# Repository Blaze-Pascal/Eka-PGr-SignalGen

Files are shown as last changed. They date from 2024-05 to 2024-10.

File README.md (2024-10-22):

# Eka-PGr-SignalGen

Eka-PGr-SignalGen is a project designed for signal generation circuits, featuring schematic and PCB design using KiCad and simulations in LTSpice. It includes a Bill of Materials for easy component sourcing.
Features:

    KiCad project files for PCB design
    LTSpice simulation files
    BOM generation for parts

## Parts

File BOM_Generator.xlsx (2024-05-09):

 |  |  |  |  | X= | 2
lp. | ELEMENT | SYMBOL | ILOSC 1 | CENA ZA 1 | KOD TME | ILOSC NA X | CENA ZA X | OBUDOWA | LINK
1. | LM337 | LM337_TO220 | 1 | 4.332 | LM337SP | 2 | 8.664 | TO220 | https://www.tme.eu/pl/details/lm337sp/stabilizatory-napiecia-regulowane/stmicroelectronics/
2. | LM317 | LM317_TO-220 | 1 | 3.076 | LM317MABTG | 2 | 6.152 | TO220 | https://www.tme.eu/pl/details/lm317mabtg/stabilizatory-napiecia-regulowane/onsemi/
3. | LM7805 | LM7805_TO220 | 1 | 1.364 | LM7805-CDI | 2 | #VALUE! | TO220 | https://www.tme.eu/pl/details/lm7805-cdi/stabilizatory-napiecia-nieregulowane/cdil/lm7805/
4. | MC34063 | MC34063AP | 1 | 1.113 | MC34063AGN-TT | 2 | #VALUE! | DIP8 | https://www.tme.eu/pl/details/mc34063agn-tt/regulatory-napiecia-uklady-dc-dc/taejin-technology-htc-korea/mc34063agn/
5. |  |  |  | 2.365 | MC34063ACN | 0 | #VALUE! | DIP8 | https://www.tme.eu/pl/details/mc34063acn/regulatory-napiecia-uklady-dc-dc/stmicroelectronics/
6. | 1N4007 | 1N4007 | 4 | 0.7852 | 1N4007FLTR-SMC | 8 | 6.2816 | SOD123F | https://www.tme.eu/pl/details/1n4007fltr-smc/diody-uniwersalne-smd/smc-diode-solutions/1n4007fltr/
7. |  |  |  |  |  | 0 | 0
8. | LM318 | LM318H | 1 | 4.116 | LM318N/NOPB | 2 | 8.232 | DIP8 | https://www.tme.eu/pl/details/lm318n_nopb/wzmacniacze-operacyjne-tht/texas-instruments/
9. | BD135 | BD135 | 1 | 0.729 | BD135-16-CDI | 2 | 1.458 | TO126 | https://www.tme.eu/pl/details/bd135-16-cdi/tranzystory-npn-tht/cdil/tbd135-16/
10. | BD136 | BD136 | 1 | 0.639 | BD136-16-CDI | 2 | 1.278 | TO126 | https://www.tme.eu/pl/details/bd136-16-cdi/tranzystory-pnp-tht/cdil/tbd136-16/
11. | 1N4118 | 1N4118 | 2 | 0.3899 | 1N4148TA | 4 | 1.5596 | DO35 | https://www.tme.eu/pl/details/1n4148ta/diody-uniwersalne-tht/onsemi/
12. | Kondensator 3,3p | C13 | 1 | 0.6305 | 08055A3R3CAT2A | 2 | 1.261 | 805 | https://www.tme.eu/pl/details/08055a3r3cat2a/kondensatory-mlcc-smd/kyocera-avx/
13. | Kondensator 100n |  | 9 | 0.314 | CC0805KKX7R0BB104 | 18 | 5.652 | 805 | https://www.tme.eu/pl/details/cc0805kkx7r0bb104/kondensatory-mlcc-smd/yageo/
14. | Kondensator 100u | C4,C6,C11,C12, C18, C19 | 6 | 0.554 | UVY1E101MDD | 12 | 6.648 | Radial 5mm | https://www.tme.eu/pl/details/uvy1e101mdd/kondensatory-elektrolityczne-tht/nichicon/
15. | Kondensator 470p | C5 | 1 | 0.53 | 08055A471JAT2A | 2 | 1.06 | 805 | https://www.tme.eu/pl/details/08055a471jat2a/kondensatory-mlcc-smd/kyocera-avx/
16. | Kondensator 10u |  | 4 | 0.334 | GRC00AA1001HTNL | 8 | 2.672 | 5x11mm | https://www.tme.eu/pl/details/grc00aa1001htnl/kondensatory-elektrolityczne-tht/vishay/
17. |  |  |  |  |  | 0 | 0
18. |  |  |  |  |  | 0 | 0
19.
20. | Rezystor 0,2 | R1 | 1 |  | ? | 2 | 0 | 805 | ?
21. | Rezystor 18k | R3 | 1 | 0.1 | ERJ6ENF1802V | 2 | 0.2 | 805 | https://www.tme.eu/pl/details/erj6enf1802v/rezystory-smd/panasonic/
22. | Potencjometr 1k | R4, R5, R37 | 3 | 1.12 | 3305SMD-1K | 6 | 6.72 | ? | https://www.tme.eu/pl/details/3305smd-1k/potencjometry-smd-jednoobrotowe/sr-passives/
23. | Rezystor 100 | R6,R7,R39,R40 | 4 | 0.26 | RT0805FRE07100RL | 8 | 2.08 | 805 | https://www.tme.eu/pl/details/rt0805fre07100rl/rezystory-smd/yageo/
24. | Rezystor 20k | R32 | 1 | 0.218 | ERJ6ENF2002V | 2 | 0.436 | 805 | https://www.tme.eu/pl/details/erj6enf2002v/rezystory-smd/panasonic/
25. | Rezystor x | R33 |  |  |  | 0 | 0 | 805
26. | Rezystor x | R34 |  |  |  | 0 | 0 | 805
27. | Rezystor 27 | R35 | 1 | 0.582 | AR0805-27R-0.1% | 2 | 1.164 | 805 | https://www.tme.eu/pl/details/ar0805-27r-0.1%25/rezystory-smd/viking/ar05btcw0270/
 | Rezystor 1k | R36, R38 | 2 | 0.133 | ERJ6ENF1001V | 4 | 0.532 | 805 | https://www.tme.eu/pl/details/erj6enf1001v/rezystory-smd/panasonic/
 | Rezystor 3,3 | R41, R42 | 2 | 0.61 | CRCW25123R30JNTHBC | 4 | 2.44 | 2512 | https://www.tme.eu/pl/details/crcw25123r30jnthbc/rezystory-smd/vishay/
 | Rezystor 2k 0,1% |  |  |  |  | 0 | 0
 | Rezystor 100 1w |  | 2 | 0.354 | CRCW2512100RJNTHBC |  |  | 2512 | https://www.tme.eu/pl/details/crcw2512100rjnthbc/rezystory-smd/vishay/
 | Dioda 1N5818 | D2 | 1 | 1.29 | 1N5818-DC | 2 | 2.58 | DO41 | https://www.tme.eu/pl/details/1n5818-dc/diody-schottky-tht/dc-components/1n5818/
 | Dioda 1N4007 | D3,D4,D5,D6 | 4 | 0.728 | 1N4007FLTR-SMC | 8 | 5.824 | SOD123F | https://www.tme.eu/pl/details/1n4007fltr-smc/diody-uniwersalne-smd/smc-diode-solutions/1n4007fltr/
 | Dioda 1N4148 | D7, D8 | 2 | 0.159 | 1N4148W-AQ-DIO | 4 | 0.636 | SOD123F | https://www.tme.eu/pl/details/1n4148w-aq-dio/diody-uniwersalne-smd/diotec-semiconductor/1n4148w-aq/
 |  |  |  |  |  | 0 | 0
 | Cewka 100u | L1 | 1 | 4.85 | SBC4-101-102 | 2 | 9.7 |  | https://www.tme.eu/pl/details/sbc4-101-102/dlawiki-pionowe/kemet/
 |  |  |  | 1.39 | RLB0914-101KL | 0 | 0 |  | https://www.tme.eu/pl/details/rlb0914-101kl/dlawiki-pionowe/bourns/
 | Złącze BNC | Conn_Coaxial | 1 | 7.37 | RF15006 | 2 | 14.74 | BNC | https://www.tme.eu/pl/details/rf15006/zlacza-bnc/adam-tech/rf1-500-6/
 |  |  | 1 | 9.75 | B6252H5NPP3G50 | 2 | 19.5 | BNC | https://www.tme.eu/pl/details/b6252h5npp3g50/zlacza-bnc/amphenol-rf/b6252h5-npp3g-50/
 |  |  |  |  |  | 0 | 0
 | Tranzystor BC817 | Q3 | 1 | 0.111 | BC817-QR | 2 | 0.222 | SOT23 | https://www.tme.eu/pl/details/bc817-qr/tranzystory-npn-smd/nexperia/
 | Przekaźnik |  | 1 | 1.922 | LEG-1A-5 | 2 | 3.844 | ? | https://www.tme.eu/pl/details/leg-1a-5/przekazniki-elektromagn-miniaturowe/recoy-rayex-electronics/leg1a-5/
 |  |  |  |  |  | 0 | 0
 |  |  |  |  |  | 0 | 0
 | Bezpiecznik topikowy |  |  |  |  | 0 | 0
 | Gniazdo bezpiecznikowe |  |  |  |  | 0 | 0

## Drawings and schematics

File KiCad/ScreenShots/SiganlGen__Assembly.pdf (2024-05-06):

A

A

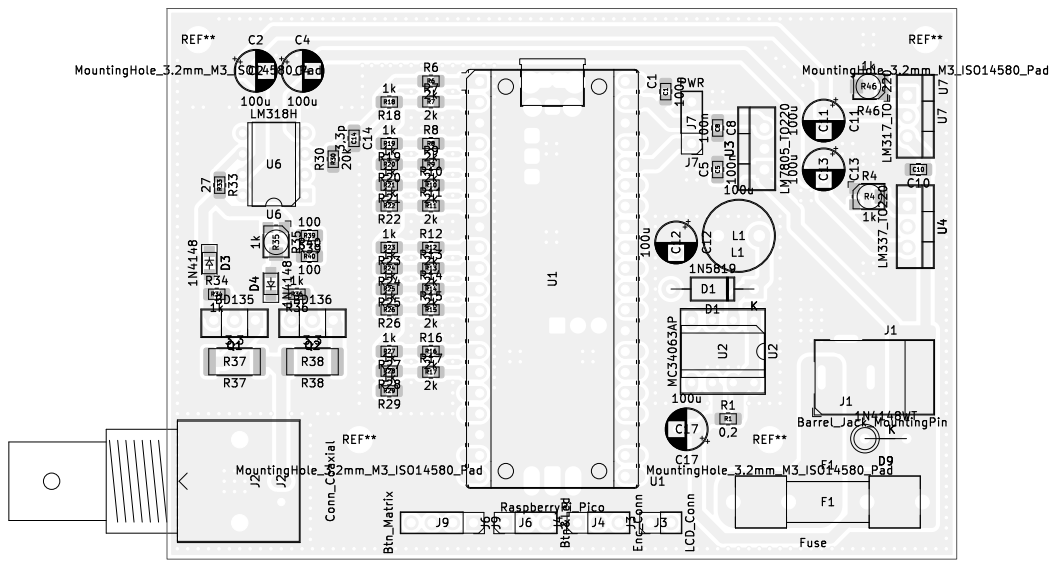
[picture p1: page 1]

Id: 1/1 Title: File: SiganlGen.kicad_pcb Sheet:

C19 C3 D7 | R2 | C18 C16 1 | 2 | 3 | 4 | 5 | 6 1 | 2 | 3 | 4 | 5 | 6 ABCD | ABCD Date: KiCad | E.D.A. 8.0.1 Size: A4 | Rev:
C18 100n | C16

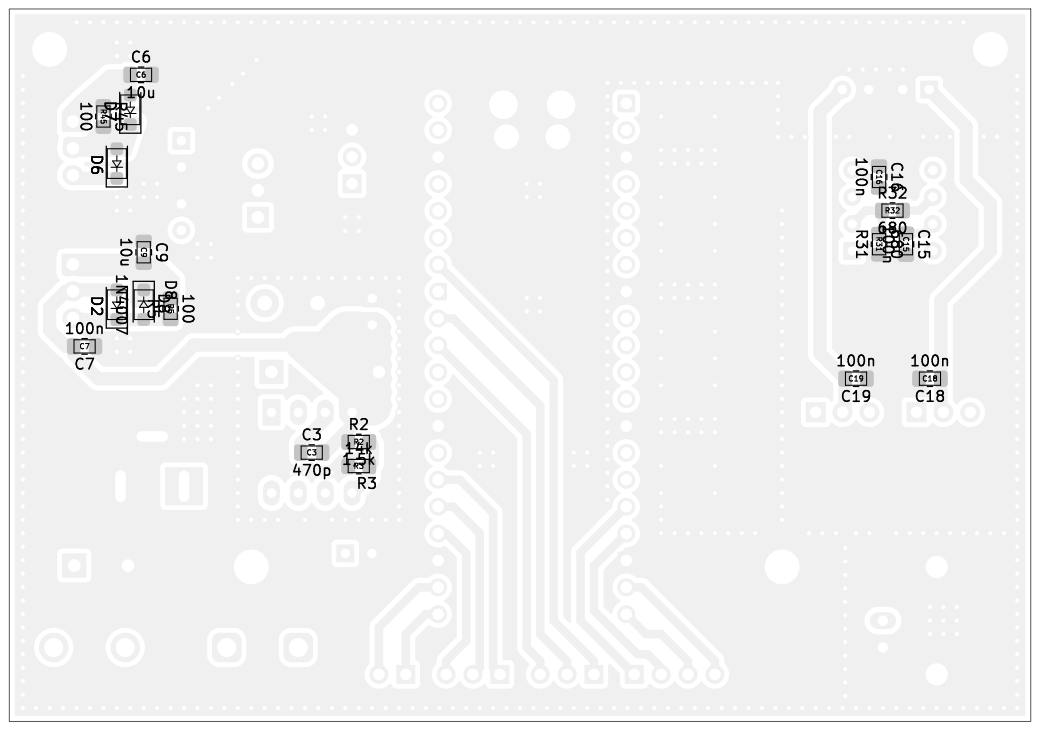
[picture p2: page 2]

Id: 1/1 Title: File: SiganlGen.kicad_pcb Sheet:

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

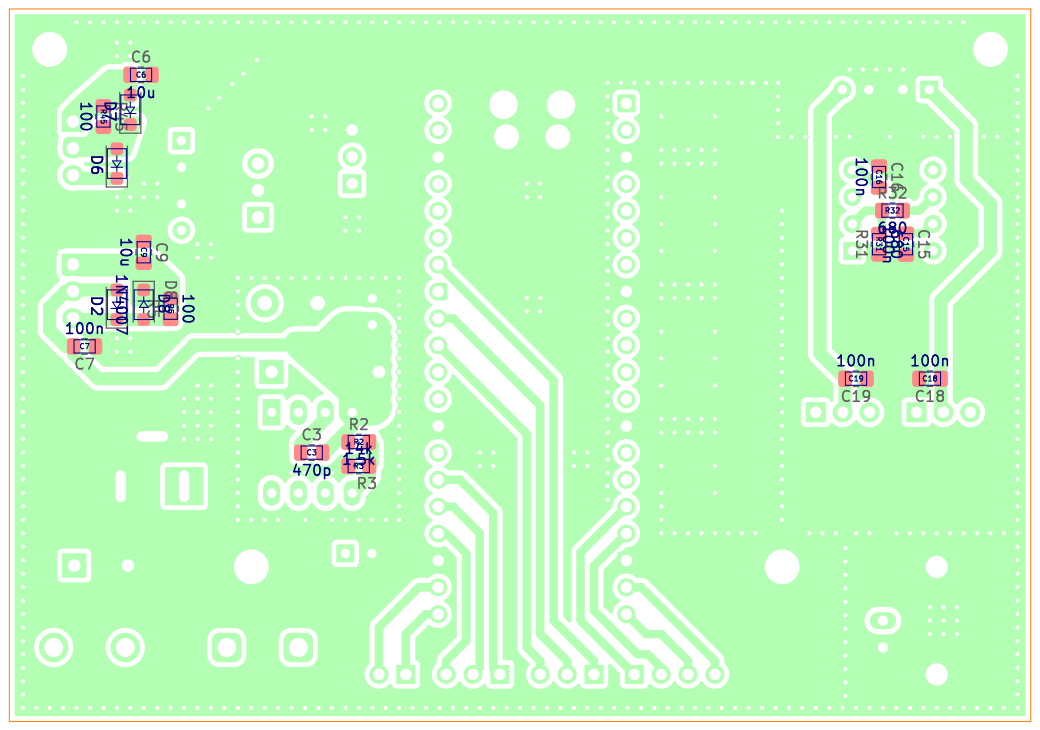
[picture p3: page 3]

Id: 1/1 Title: File: SiganlGen.kicad_pcb Sheet:

A

A

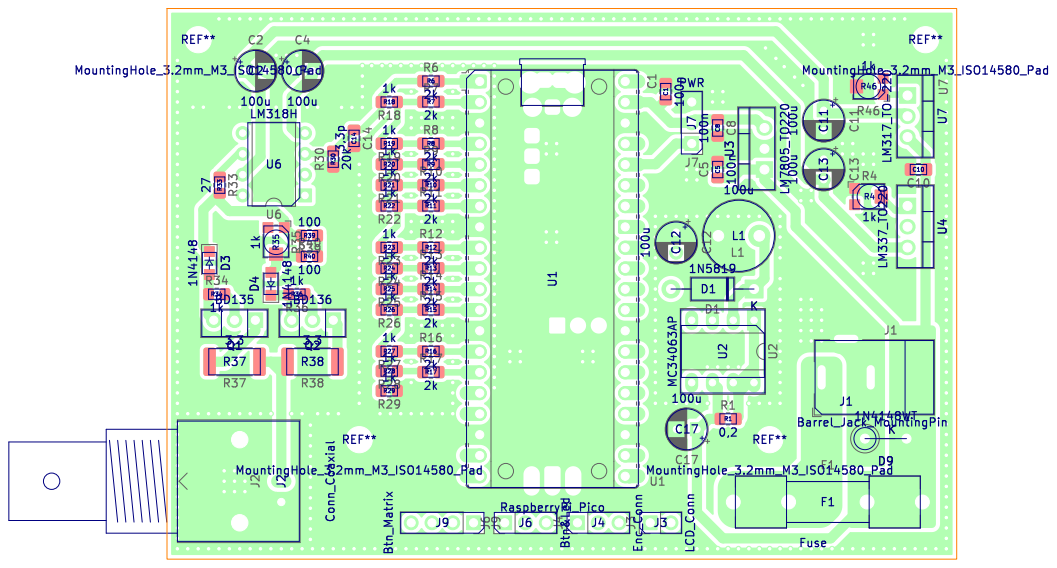
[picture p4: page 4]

Id: 1/1 Title: File: SiganlGen.kicad_pcb Sheet:

# Out Exposed Copper Keep Out Board Keep Out USB Cable USB Cable

## circle shown Wiper may be

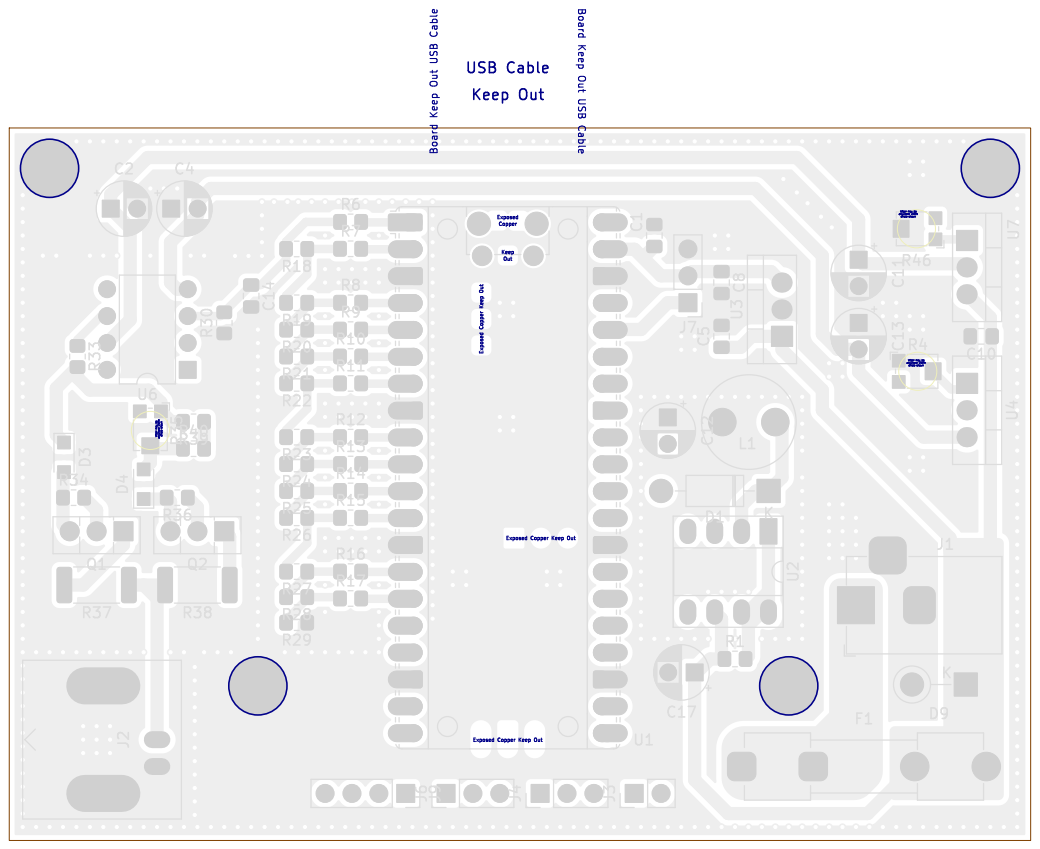
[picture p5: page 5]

Keep Copper Wiper may be anywhere within circle shown

Exposed Copper Keep Out

Id: 1/1 Title: File: SiganlGen.kicad_pcb Sheet:

A

A

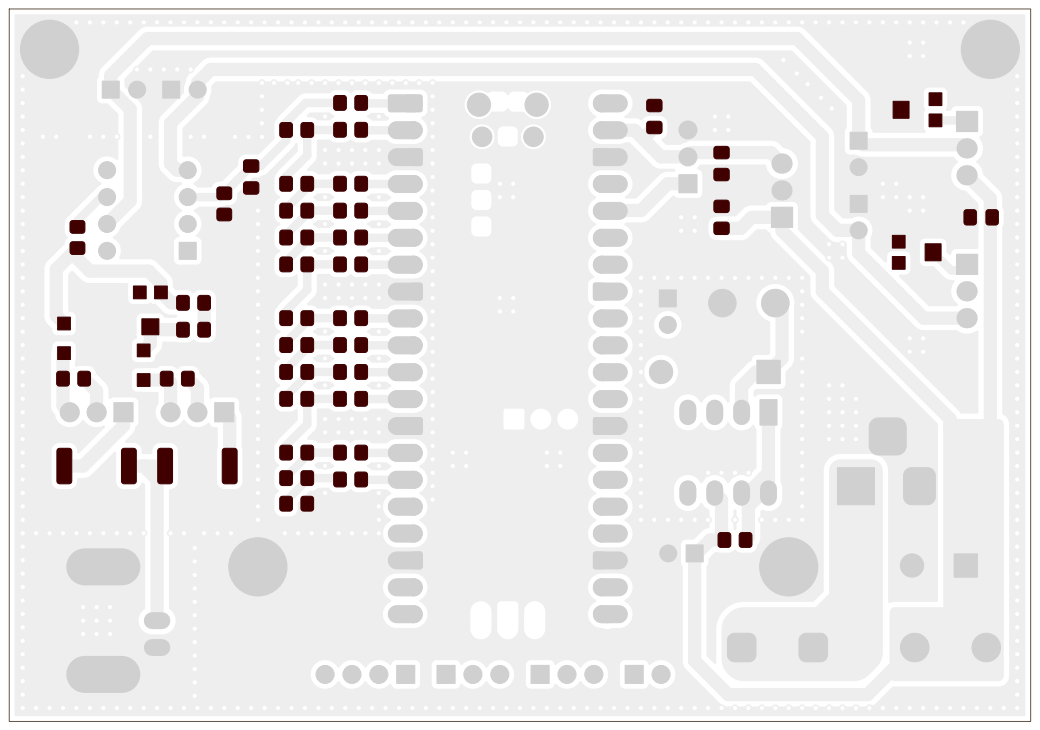
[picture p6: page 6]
D Date: KiCad; E.D.A. 8.0.1 Size: A4; Rev:

Id: 1/1 Title: File: SiganlGen.kicad_pcb Sheet:

C18 100n | C16 1 | 2 | 3 | 4 | 5 | 6 1 | 2 | 3 | 4 | 5 | 6 ABCD | ABCD Date: KiCad | E.D.A. 8.0.1 Size: A4 | Rev:

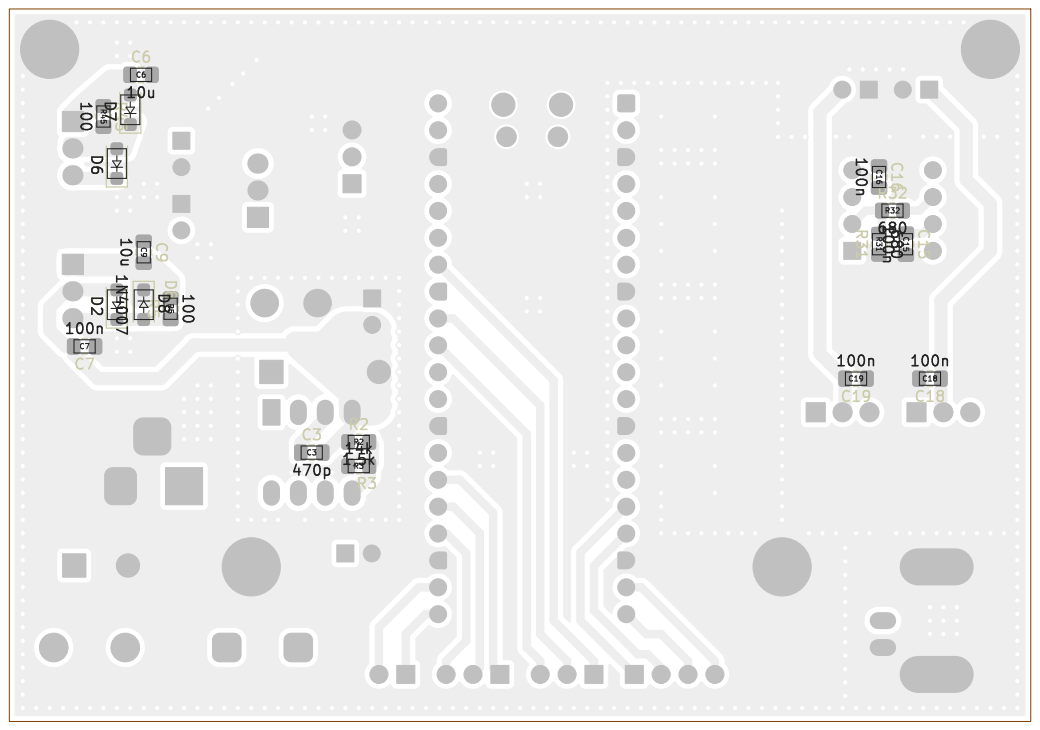
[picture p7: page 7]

Id: 1/1 Title: File: SiganlGen.kicad_pcb Sheet:

R15 1k
R8 1k

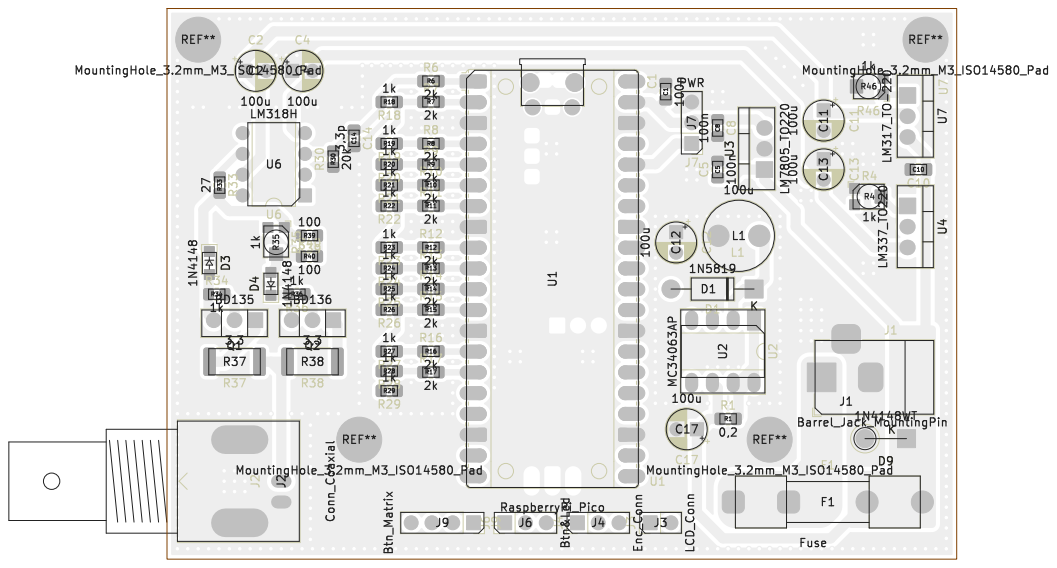
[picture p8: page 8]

Id: 1/1 Title: File: SiganlGen.kicad_pcb Sheet:

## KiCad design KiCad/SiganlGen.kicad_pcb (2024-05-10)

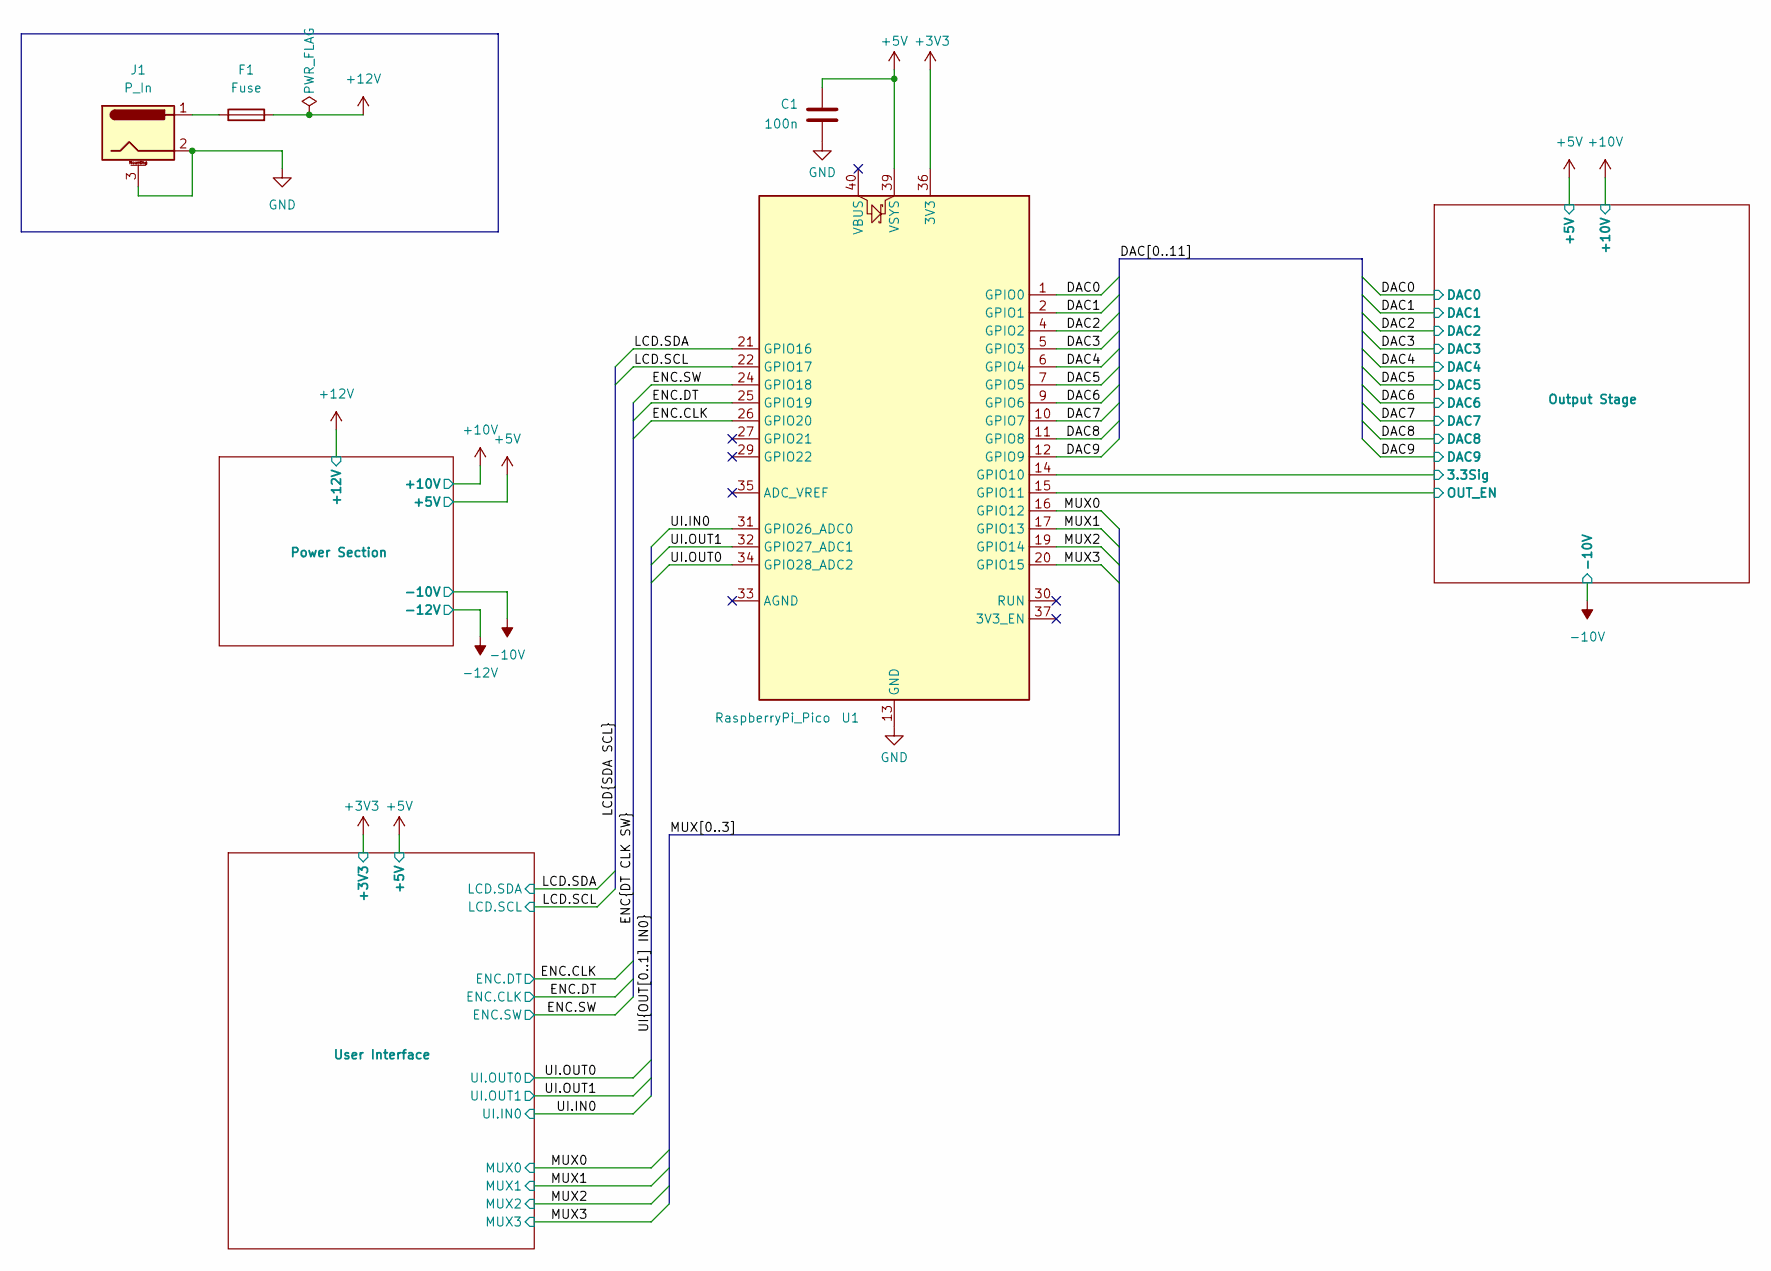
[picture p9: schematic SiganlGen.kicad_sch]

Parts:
C1: 100n; C_0805_2012Metric_Pad1.18x1.45mm_HandSolder
F1: Fuse; Fuseholder_Clip-5x20mm_Keystone_3517_Inline_P23.11x6.76mm_D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
J1: P_In; BarrelJack_Horizontal
U1: RaspberryPi_Pico; RaspberryPi_Pico_Common

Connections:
+3V3: U1.36 (3V3); also elsewhere on the board
+5V: C1.1, U1.39 (VSYS); also elsewhere on the board
+12V: F1.2; also elsewhere on the board
/DAC0: U1.1 (GPIO0); also elsewhere on the board
/DAC1: U1.2 (GPIO1); also elsewhere on the board
/DAC2: U1.4 (GPIO2); also elsewhere on the board
/DAC3: U1.5 (GPIO3); also elsewhere on the board
/DAC4: U1.6 (GPIO4); also elsewhere on the board
/DAC5: U1.7 (GPIO5); also elsewhere on the board
/DAC6: U1.9 (GPIO6); also elsewhere on the board
/DAC7: U1.10 (GPIO7); also elsewhere on the board
/DAC8: U1.11 (GPIO8); also elsewhere on the board
/DAC9: U1.12 (GPIO9); also elsewhere on the board
/ENC.CLK: U1.26 (GPIO20); also elsewhere on the board
/ENC.DT: U1.25 (GPIO19); also elsewhere on the board
/ENC.SW: U1.24 (GPIO18); also elsewhere on the board
/LCD.SCL: U1.22 (GPIO17); also elsewhere on the board
/LCD.SDA: U1.21 (GPIO16); also elsewhere on the board
/MUX0: U1.16 (GPIO12); also elsewhere on the board
/MUX1: U1.17 (GPIO13); also elsewhere on the board
/MUX2: U1.19 (GPIO14); also elsewhere on the board
/MUX3: U1.20 (GPIO15); also elsewhere on the board
/Output Stage/3.3Sig: U1.14 (GPIO10); also elsewhere on the board
/Output Stage/OUT_EN: U1.15 (GPIO11); also elsewhere on the board
/UI.IN0: U1.31 (GPIO26_ADC0); also elsewhere on the board
/UI.OUT0: U1.34 (GPIO28_ADC2); also elsewhere on the board
/UI.OUT1: U1.32 (GPIO27_ADC1); also elsewhere on the board
GND: C1.2, J1.2, J1.3 (MountPin), U1.3 (GND), U1.8 (GND), U1.13 (GND), U1.18 (GND), U1.23 (GND), U1.28 (GND), U1.38 (GND); also elsewhere on the board
unnamed: F1.1, J1.1

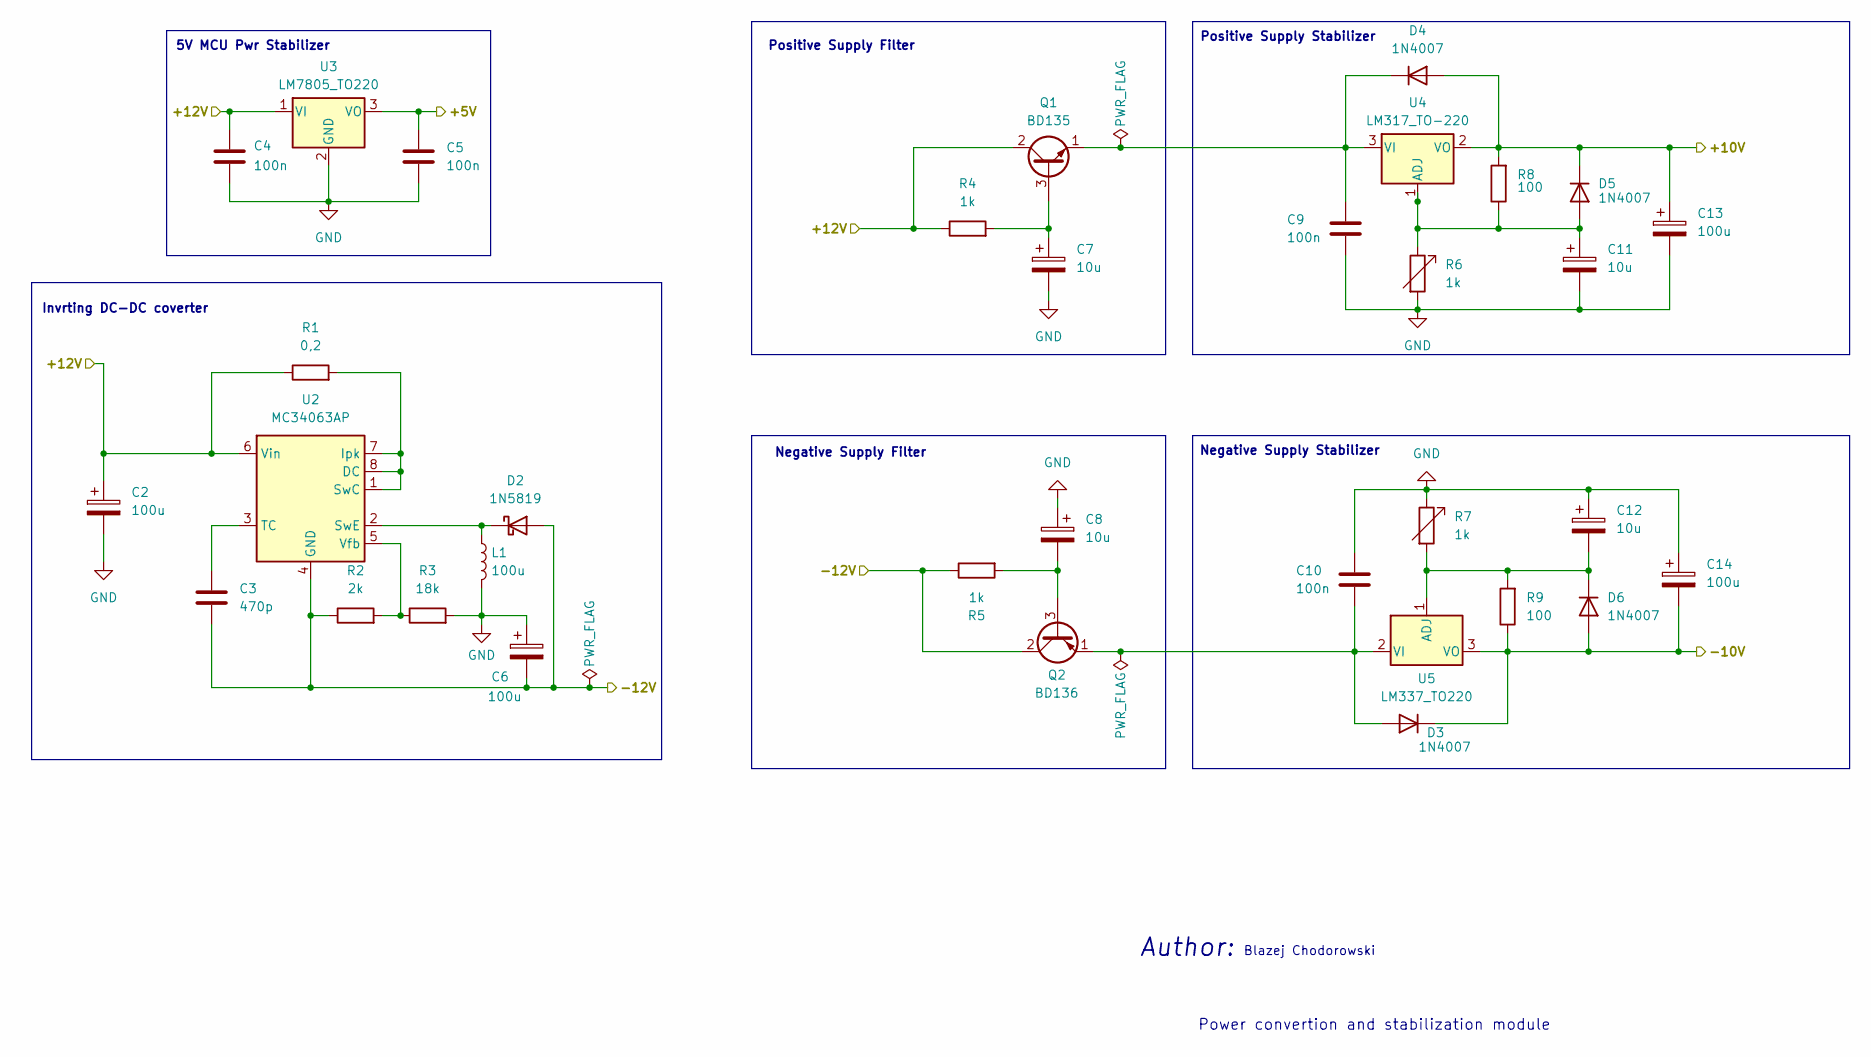
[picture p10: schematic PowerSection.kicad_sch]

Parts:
C2, C6, C13, C14: 100u; CP_Radial_D5.0mm_P2.50mm
C3: 470p; C_0805_2012Metric_Pad1.18x1.45mm_HandSolder
C4, C5, C9, C10: 100n; C_0805_2012Metric_Pad1.18x1.45mm_HandSolder
C7, C8, C11, C12: 10u; CP_Radial_D5.0mm_P2.00mm
D2: 1N5819; D_DO-41_SOD81_P10.16mm_Horizontal
D3, D4, D5, D6: 1N4007; D_SOD-123F
L1: 100u; L_Radial_D8.7mm_P5.00mm_Fastron_07HCP
Q1: BD135; TO-126-3_Vertical
Q2: BD136; TO-126-3_Vertical
R1: 0,2; R_0805_2012Metric_Pad1.20x1.40mm_HandSolder
R2: 2k; R_0805_2012Metric_Pad1.20x1.40mm_HandSolder
R3: 18k; R_0805_2012Metric_Pad1.20x1.40mm_HandSolder
R4, R5: 1k; R_0805_2012Metric_Pad1.20x1.40mm_HandSolder
R6, R7: 1k; Potentiometer_Bourns_TC33X_Vertical
R8, R9: 100; R_0805_2012Metric_Pad1.20x1.40mm_HandSolder
U2: MC34063AP; DIP-8_W7.62mm_Socket_LongPads
U3: LM7805_TO220; TO-220-3_Horizontal_TabDown
U4: LM317_TO-220; TO-220-3_Vertical
U5: LM337_TO220; TO-220-3_Vertical

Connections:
+5V: C5.1, U3.3 (VO); also elsewhere on the board
+10V: C13.1, D4.2 (A), D5.1 (K), R8.2, U4.2 (VO); also elsewhere on the board
+12V: C2.1, C4.1, Q1.2 (C), R1.1, R4.1, U2.6 (Vin), U3.1 (VI); also elsewhere on the board
-10V: C14.2, D3.1 (K), D6.2 (A), R9.1, U5.3 (VO); also elsewhere on the board
-12V: C3.2, C6.2, D2.2 (A), Q2.2 (C), R2.1, R5.1, U2.4 (GND)
GND: C2.2, C4.2, C5.2, C6.1, C7.2, C8.1, C9.2, C10.1, C11.2, C12.1, C13.2, C14.1, L1.2, R3.2, R6.2, R7.1, U3.2 (GND); also elsewhere on the board
unnamed: D2.1 (K), L1.1, U2.2 (SwE)
unnamed: C10.2, D3.2 (A), Q2.1 (E), U5.2 (VI)
unnamed: C9.1, D4.1 (K), Q1.1 (E), U4.3 (VI)
unnamed: C11.1, D5.2 (A), R6.1, R8.1, U4.1 (ADJ)
unnamed: C12.2, D6.1 (K), R7.2, R9.2, U5.1 (ADJ)
unnamed: C7.1, Q1.3 (B), R4.2
unnamed: C8.2, Q2.3 (B), R5.2
unnamed: R1.2, U2.1 (SwC), U2.7 (Ipk), U2.8 (DC)
unnamed: C3.1, U2.3 (TC)
unnamed: R2.2, R3.1, U2.5 (Vfb)

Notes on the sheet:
Author:
Positive Supply Filter
Blazej Chodorowski
Power convertion and stabilization module
5V MCU Pwr Stabilizer
Positive Supply Stabilizer
Invrting DC-DC coverter
Negative Supply Stabilizer
Negative Supply Filter

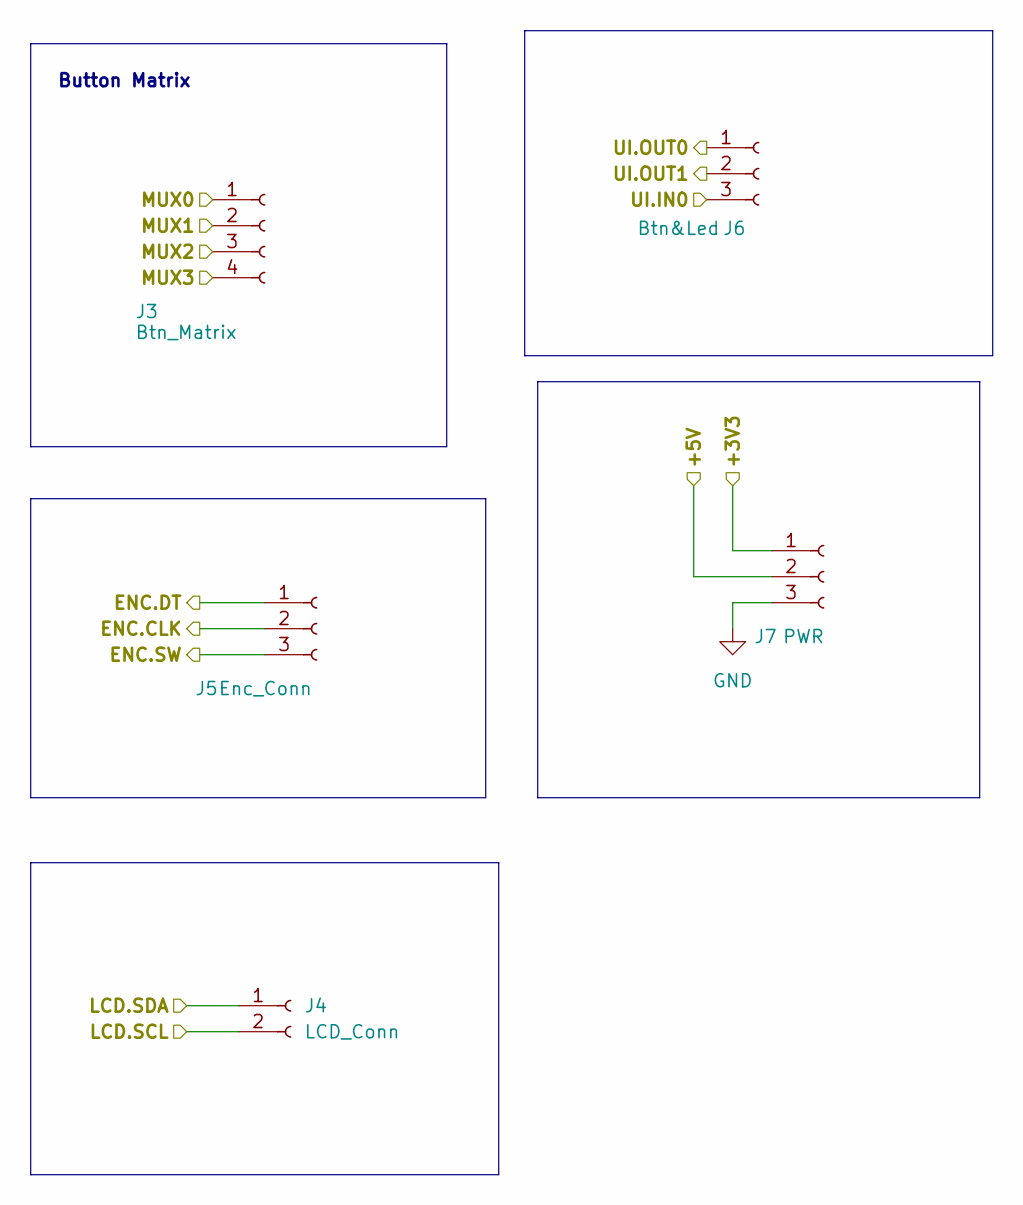
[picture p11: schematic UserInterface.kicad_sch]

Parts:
J3: Btn_Matrix; PinSocket_1x04_P2.54mm_Vertical
J4: LCD_Conn; PinHeader_1x02_P2.54mm_Vertical
J5: Enc_Conn; PinHeader_1x03_P2.54mm_Vertical
J6: Btn&Led; PinHeader_1x03_P2.54mm_Vertical
J7: PWR; PinHeader_1x03_P2.54mm_Vertical

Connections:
+3V3: J7.1; also elsewhere on the board
+5V: J7.2; also elsewhere on the board
/ENC.CLK: J5.1; also elsewhere on the board
/ENC.DT: J5.2; also elsewhere on the board
/ENC.SW: J5.3; also elsewhere on the board
/LCD.SCL: J4.2; also elsewhere on the board
/LCD.SDA: J4.1; also elsewhere on the board
/MUX0: J3.1; also elsewhere on the board
/MUX1: J3.2; also elsewhere on the board
/MUX2: J3.3; also elsewhere on the board
/MUX3: J3.4; also elsewhere on the board
/UI.IN0: J6.3; also elsewhere on the board
/UI.OUT0: J6.1; also elsewhere on the board
/UI.OUT1: J6.2; also elsewhere on the board
GND: J7.3; also elsewhere on the board

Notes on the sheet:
Button Matrix

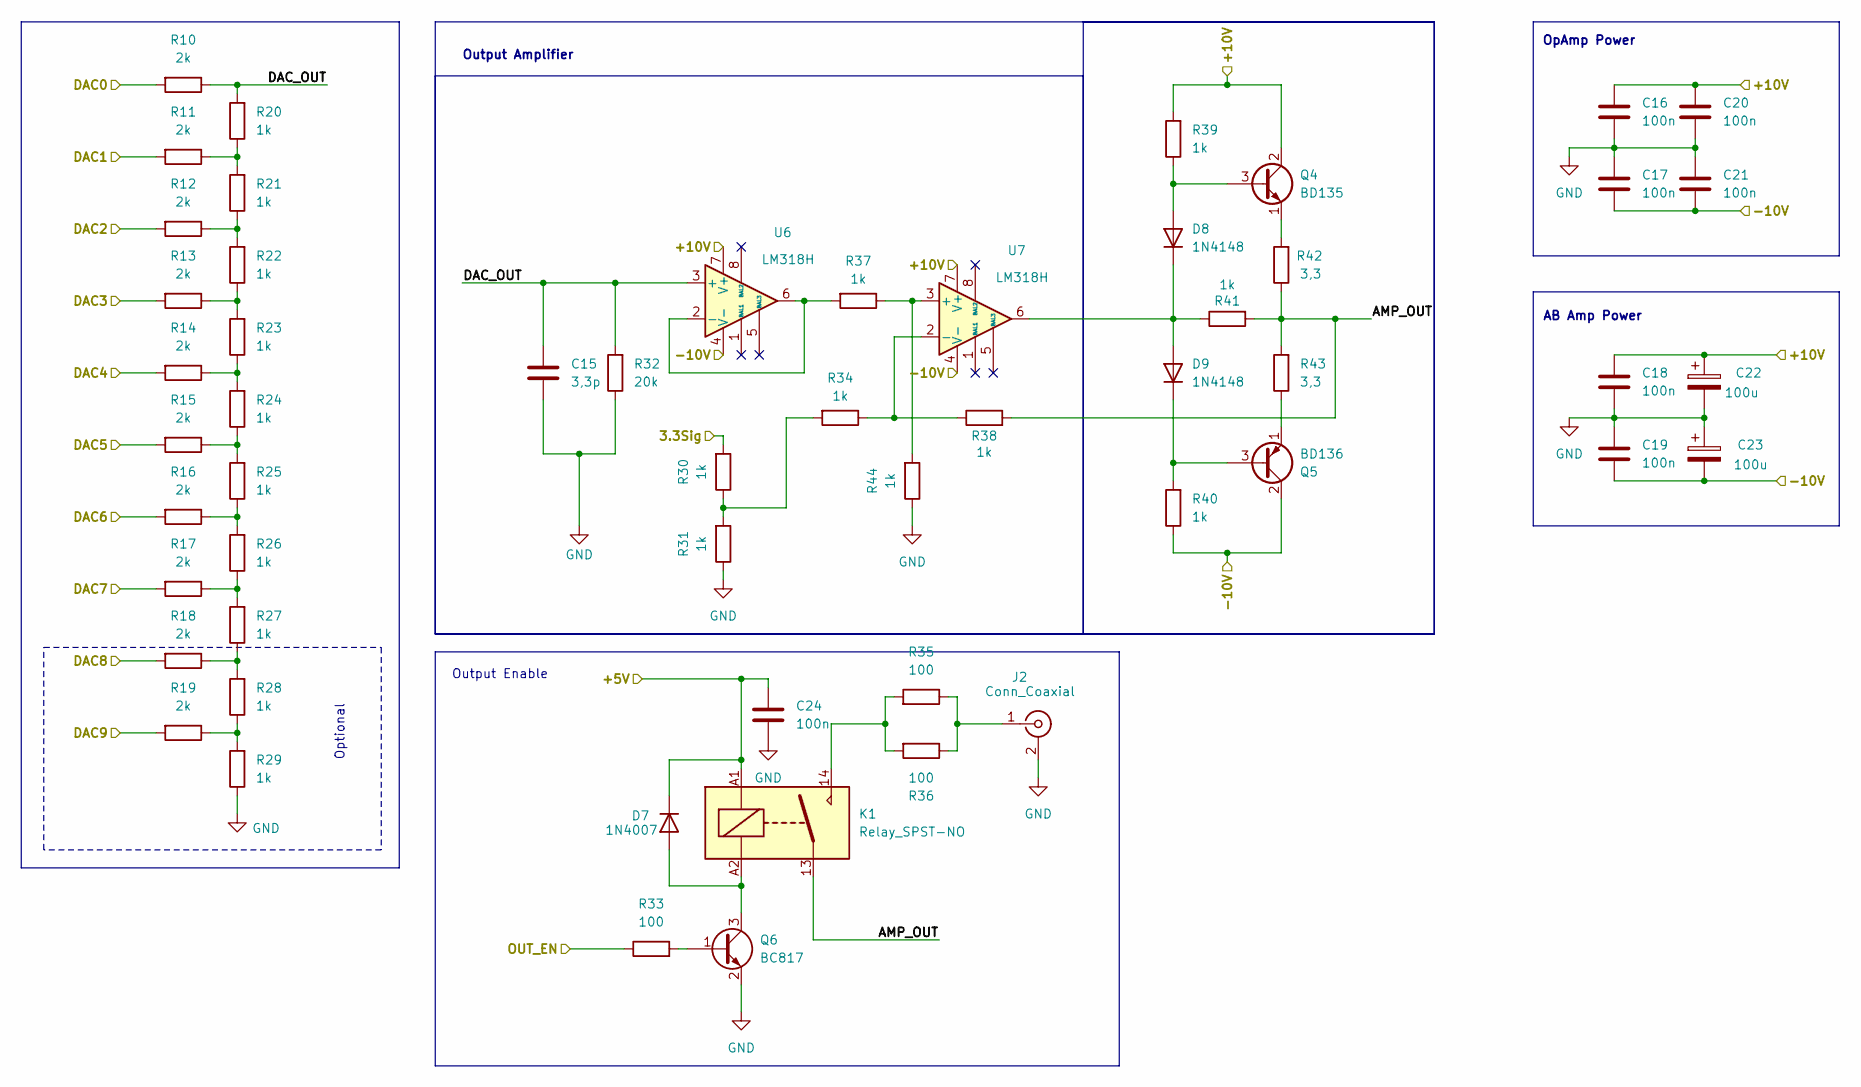
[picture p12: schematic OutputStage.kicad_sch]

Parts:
C15: 3,3p; C_0805_2012Metric_Pad1.18x1.45mm_HandSolder
C16, C17, C18, C19, C20, C21, C24: 100n; C_0805_2012Metric_Pad1.18x1.45mm_HandSolder
C22, C23: 100u; CP_Radial_D5.0mm_P2.50mm
D7: 1N4007; D_SOD-123F
D8, D9: 1N4148; Nexperia_CFP3_SOD-123W
J2: Conn_Coaxial; BNC_Amphenol_B6252HB-NPP3G-50_Horizontal
K1: Relay_SPST-NO; Relay_SPST_SANYOU_SRD_Series_Form_B
Q4: BD135; TO-126-3_Vertical
Q5: BD136; TO-126-3_Vertical
Q6: BC817; SOT-23_Handsoldering
R10, R11, R12, R13, R14, R15, R16, R17, R18, R19: 2k; R_0805_2012Metric_Pad1.20x1.40mm_HandSolder
R20, R21, R22, R23, R24, R25, R26, R27, R28, R29, R30, R31, R34, R37, R38, R39, R40, R41, R44: 1k; R_0805_2012Metric_Pad1.20x1.40mm_HandSolder
R32: 20k; R_0805_2012Metric_Pad1.20x1.40mm_HandSolder
R33: 100; R_0805_2012Metric_Pad1.20x1.40mm_HandSolder
R35, R36: 100; R_2512_6332Metric_Pad1.40x3.35mm_HandSolder
R42, R43: 3,3; R_2512_6332Metric_Pad1.40x3.35mm_HandSolder
U6, U7: LM318H; DIP-8_W7.62mm

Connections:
+5V: C24.1, D7.1 (K), K1.A1; also elsewhere on the board
+10V: C16.1, C18.1, C20.1, C22.1, Q4.2 (C), R39.2, U6.7 (V+), U7.7 (V+); also elsewhere on the board
-10V: C17.2, C19.2, C21.2, C23.2, Q5.2 (C), R40.1, U6.4 (V-), U7.4 (V-); also elsewhere on the board
/DAC0: R10.2; also elsewhere on the board
/DAC1: R11.2; also elsewhere on the board
/DAC2: R12.2; also elsewhere on the board
/DAC3: R13.2; also elsewhere on the board
/DAC4: R14.2; also elsewhere on the board
/DAC5: R15.2; also elsewhere on the board
/DAC6: R16.2; also elsewhere on the board
/DAC7: R17.2; also elsewhere on the board
/DAC8: R18.2; also elsewhere on the board
/DAC9: R19.2; also elsewhere on the board
/Output Stage/3.3Sig: R30.2; also elsewhere on the board
/Output Stage/AMP_OUT: K1.13, R38.2, R41.2, R42.1, R43.2
/Output Stage/DAC_OUT: C15.1, R10.1, R20.2, R32.2, U6.3 (+)
/Output Stage/OUT_EN: R33.1; also elsewhere on the board
GND: C15.2, C16.2, C17.1, C18.2, C19.1, C20.2, C21.1, C22.2, C23.1, C24.2, J2.2 (Ext), Q6.2 (E), R29.1, R31.1, R32.1, R44.1; also elsewhere on the board
unnamed: D7.2 (A), K1.A2, Q6.3 (C)
unnamed: D8.2 (A), Q4.3 (B), R39.1
unnamed: D8.1 (K), D9.2 (A), R41.1, U7.6
unnamed: D9.1 (K), Q5.3 (B), R40.2
unnamed: J2.1 (In), R35.1, R36.1
unnamed: K1.14, R35.2, R36.2
unnamed: Q4.1 (E), R42.2
unnamed: Q5.1 (E), R43.1
unnamed: Q6.1 (B), R33.2
unnamed: R11.1, R20.1, R21.2
unnamed: R12.1, R21.1, R22.2
unnamed: R13.1, R22.1, R23.2
unnamed: R14.1, R23.1, R24.2
unnamed: R15.1, R24.1, R25.2
unnamed: R16.1, R25.1, R26.2
unnamed: R17.1, R26.1, R27.2
unnamed: R18.1, R27.1, R28.2
unnamed: R19.1, R28.1, R29.2
unnamed: R30.1, R31.2, R34.2
unnamed: R37.2, U6.2 (-), U6.6
unnamed: R37.1, R44.2, U7.3 (+)
unnamed: R34.1, R38.1, U7.2 (-)

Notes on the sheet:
Optional
Output Enable
AB Amp Power
OpAmp Power
Output Amplifier

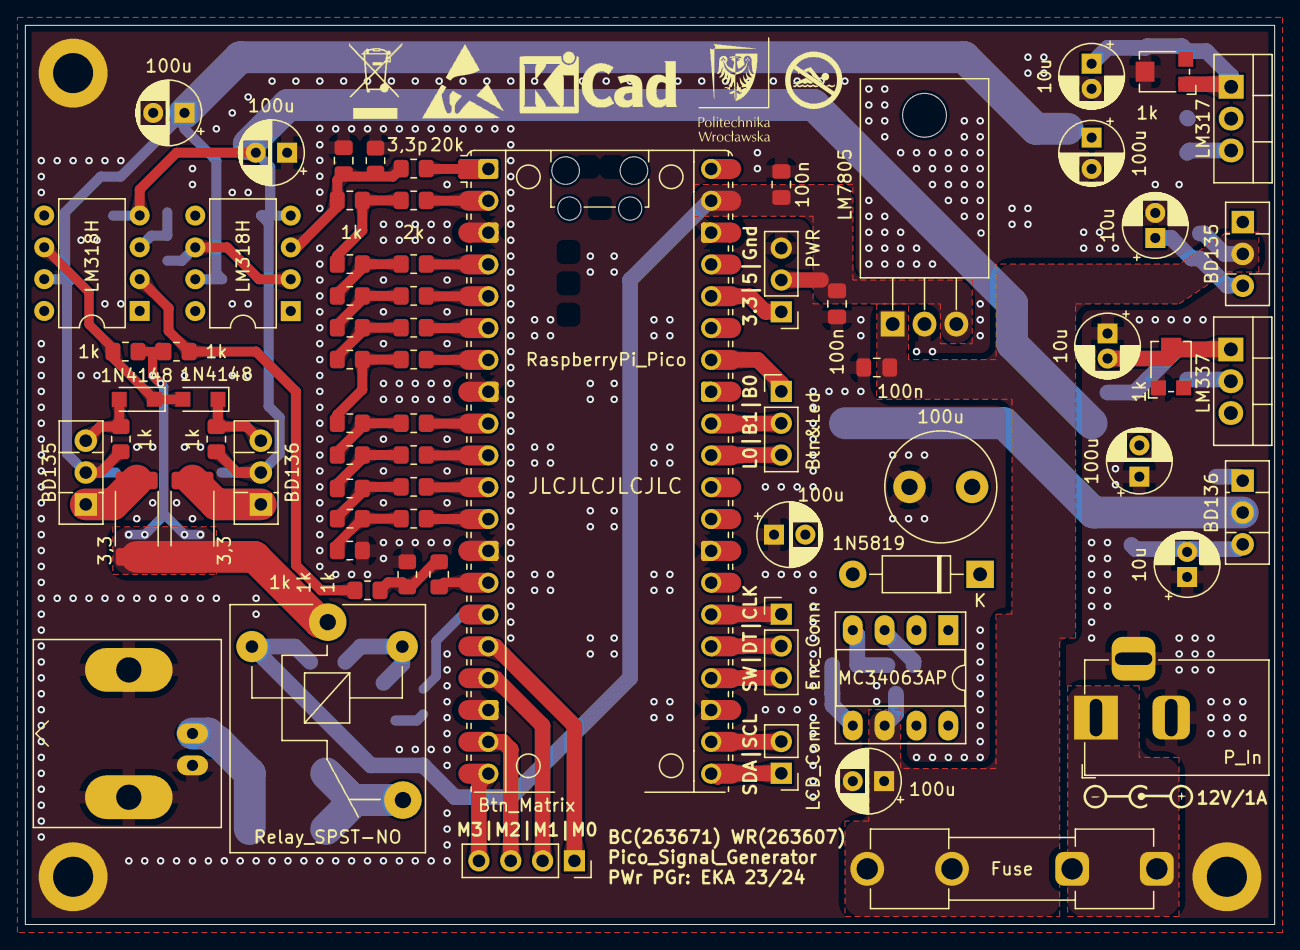
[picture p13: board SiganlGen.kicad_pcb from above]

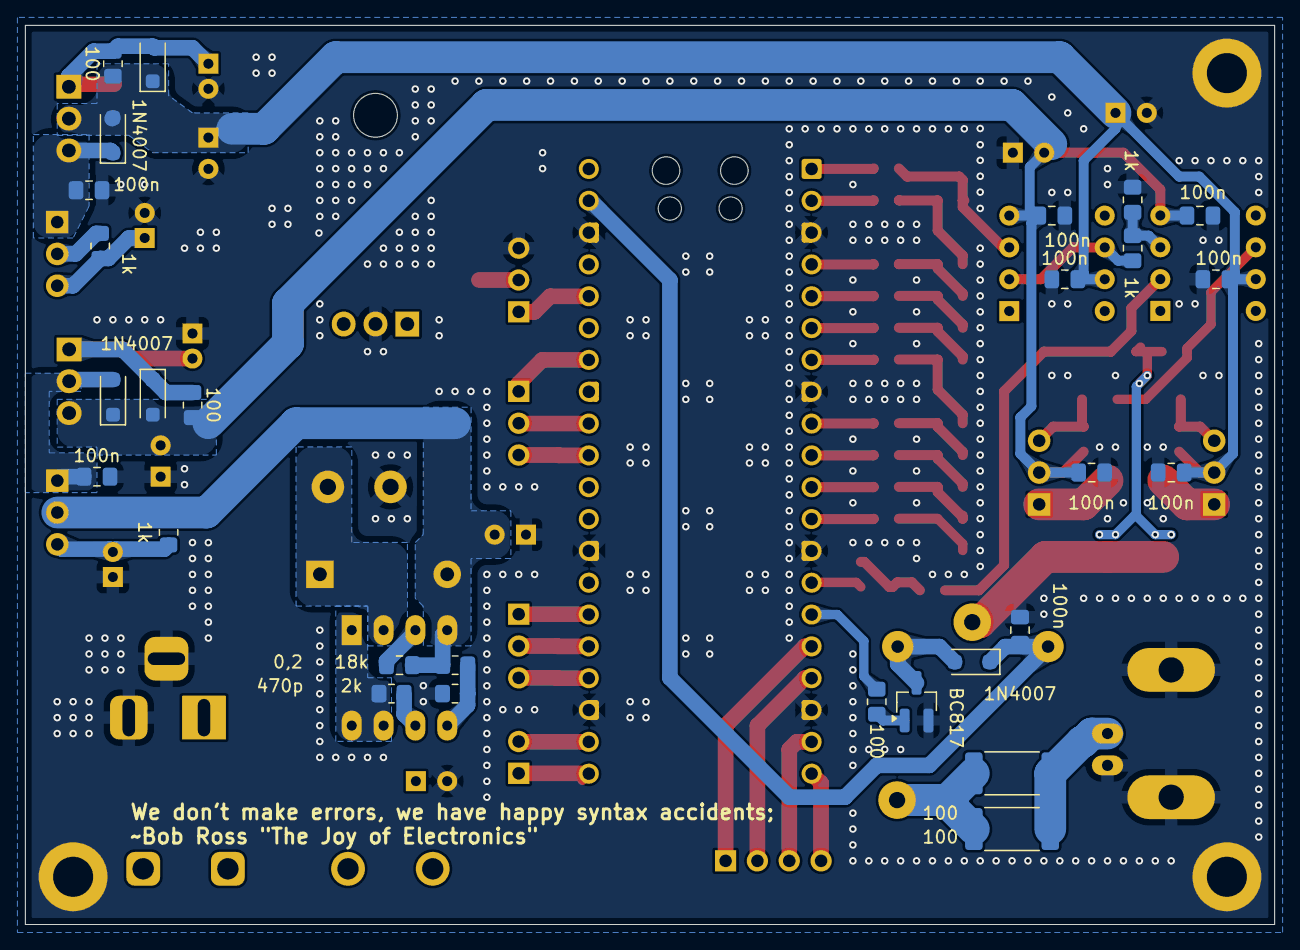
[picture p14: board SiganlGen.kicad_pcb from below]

Board: 2 copper layers, 99.7 x 71.8 mm, 98 parts (28 on the bottom side), 66 nets.

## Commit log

2024-04-29 Added program folders
    [SiganlGen.kicad_pcb, SiganlGen.kicad_sch]
2024-04-29 DAC Simulation file
    [PowerSection.kicad_sch]
2024-04-29 Partition schematic to different sheets
    [MCU.kicad_sch, OutputStage.kicad_sch, PowerSection.kicad_sch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]
2024-04-29 Added elements values
    [MCU.kicad_sch, OutputStage.kicad_sch, PowerSection.kicad_sch]
2024-04-29 Filled in schematic
    [MCU.kicad_sch, OutputStage.kicad_sch, PowerSection.kicad_sch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]
2024-04-29 Added footprints
    [MCU.kicad_sch, OutputStage.kicad_sch, PowerSection.kicad_sch]
2024-05-02 minor changes
    [OutputStage.kicad_sch, PowerSection.kicad_sch, SiganlGen.kicad_sch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]
2024-05-02 mux in ui
    [UserInterface.kicad_sch]
2024-05-03 UI connections to uC
    [OutputStage.kicad_sch, SiganlGen.kicad_pcb, SiganlGen.kicad_sch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]
2024-05-03 First DAC layout, rough board layout
    [OutputStage.kicad_sch, PowerSection.kicad_sch, SiganlGen.kicad_pcb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]
2024-05-04 bom, changed lm7810 to lm317
    [BOM_Generator.xlsx, PowerSection.kicad_sch, SiganlGen.kicad_pcb]
2024-05-05 minor changes, testing
    [OutputStage.kicad_sch, SiganlGen.kicad_sch, UserInterface.kicad_sch]
2024-05-05 Added protection elements and an additional input connector
    [SiganlGen.kicad_sch]
2024-05-05 Added/changed footprints
    [SiganlGen.kicad_sch]
2024-05-05 Changed stabilizator capacitors values
    [PowerSection.kicad_sch]
2024-05-05 Changed footprints, arrangement of elements on pcb
    [OutputStage.kicad_sch, PowerSection.kicad_sch, SiganlGen.kicad_pcb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]
2024-05-06 Tidied up schematic, changed footprints
    [BOM_Generator.xlsx, OutputStage.kicad_sch, PowerSection.kicad_sch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]
2024-05-06 Alfa version of PCB design
    [OutputStage.kicad_sch, PowerSection.kicad_sch, SiganlGen.kicad_pcb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]
2024-05-06 PCB update
    [SiganlGen.kicad_pcb]
2024-05-06 PCB design
    [OutputStage.kicad_sch, PowerSection.kicad_sch, SiganlGen.kicad_pcb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]
2024-05-09 output sim, filter sim, filter sch, output change
    [OutputStage.kicad_sch, PowerSection.kicad_sch, SiganlGen.kicad_pcb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]
2024-05-09 Updated footprints
    [BOM_Generator.xlsx, OutputStage.kicad_sch, PowerSection.kicad_sch]
2024-05-10 Final PCB version (probably)
    [OutputStage.kicad_sch, PowerSection.kicad_sch, SiganlGen.kicad_pcb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]
2024-05-10 removed solder mask under lm7805
    [SiganlGen-B_Cu.gbr, SiganlGen-B_Mask.gbr, SiganlGen-B_Silks.gbr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]
2024-05-10 Update pcb
    [SiganlGen.kicad_pcb]
2024-05-10 silkscreen art
    [SiganlGen.kicad_pcb]
